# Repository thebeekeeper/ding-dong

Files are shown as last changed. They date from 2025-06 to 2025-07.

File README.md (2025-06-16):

## r0 Assembly Notes

- I forgot IO8 needs to be high at boot to be able to program the part.  Currently connected to c6, so I won't be able to use that output for now.
- I don't have the right inductors for the regulator on hand, so I used 33uH for both.  3.3v works, but 12v is down around 1v.  I'll try the correct inductor, but it might be easier to use a 12v wall wart.  Doorbell transformers give AC, so I'd have to convert it anyways.

## Changes for r1

- Removed the 12V regulator and added a barrel jack for power input.  
- Moved the `c6` signal from IO8 to IO18.  `IO8` needs to be high to program the esp32.  I'm not planning on using USB, so IO18 should be fine.
- Added a screw terminal to signal that the button has been pressed and wired it to IO19.  Added a pull-up on the signal, but I'm not sure if I'll need it.

I wasn't thinking about how the signal will come from the button, but in a typical doorbell, the button closes a circuit that will supply us with 12-14V AC.  I could put a bridge rectifier circuit in, and just use that but then I will only have power while the button is held down.  I think the best option would to use  12v wall wart and signal the bell to activate either by:
	1. A small circuit that detects when the low side of the doorbell transformer turns on and sends a 3.3v signal to my board
	2. Something wireless
So either way, the driver board will just expect a 3.3v signal and start the sequence when it gets the signal

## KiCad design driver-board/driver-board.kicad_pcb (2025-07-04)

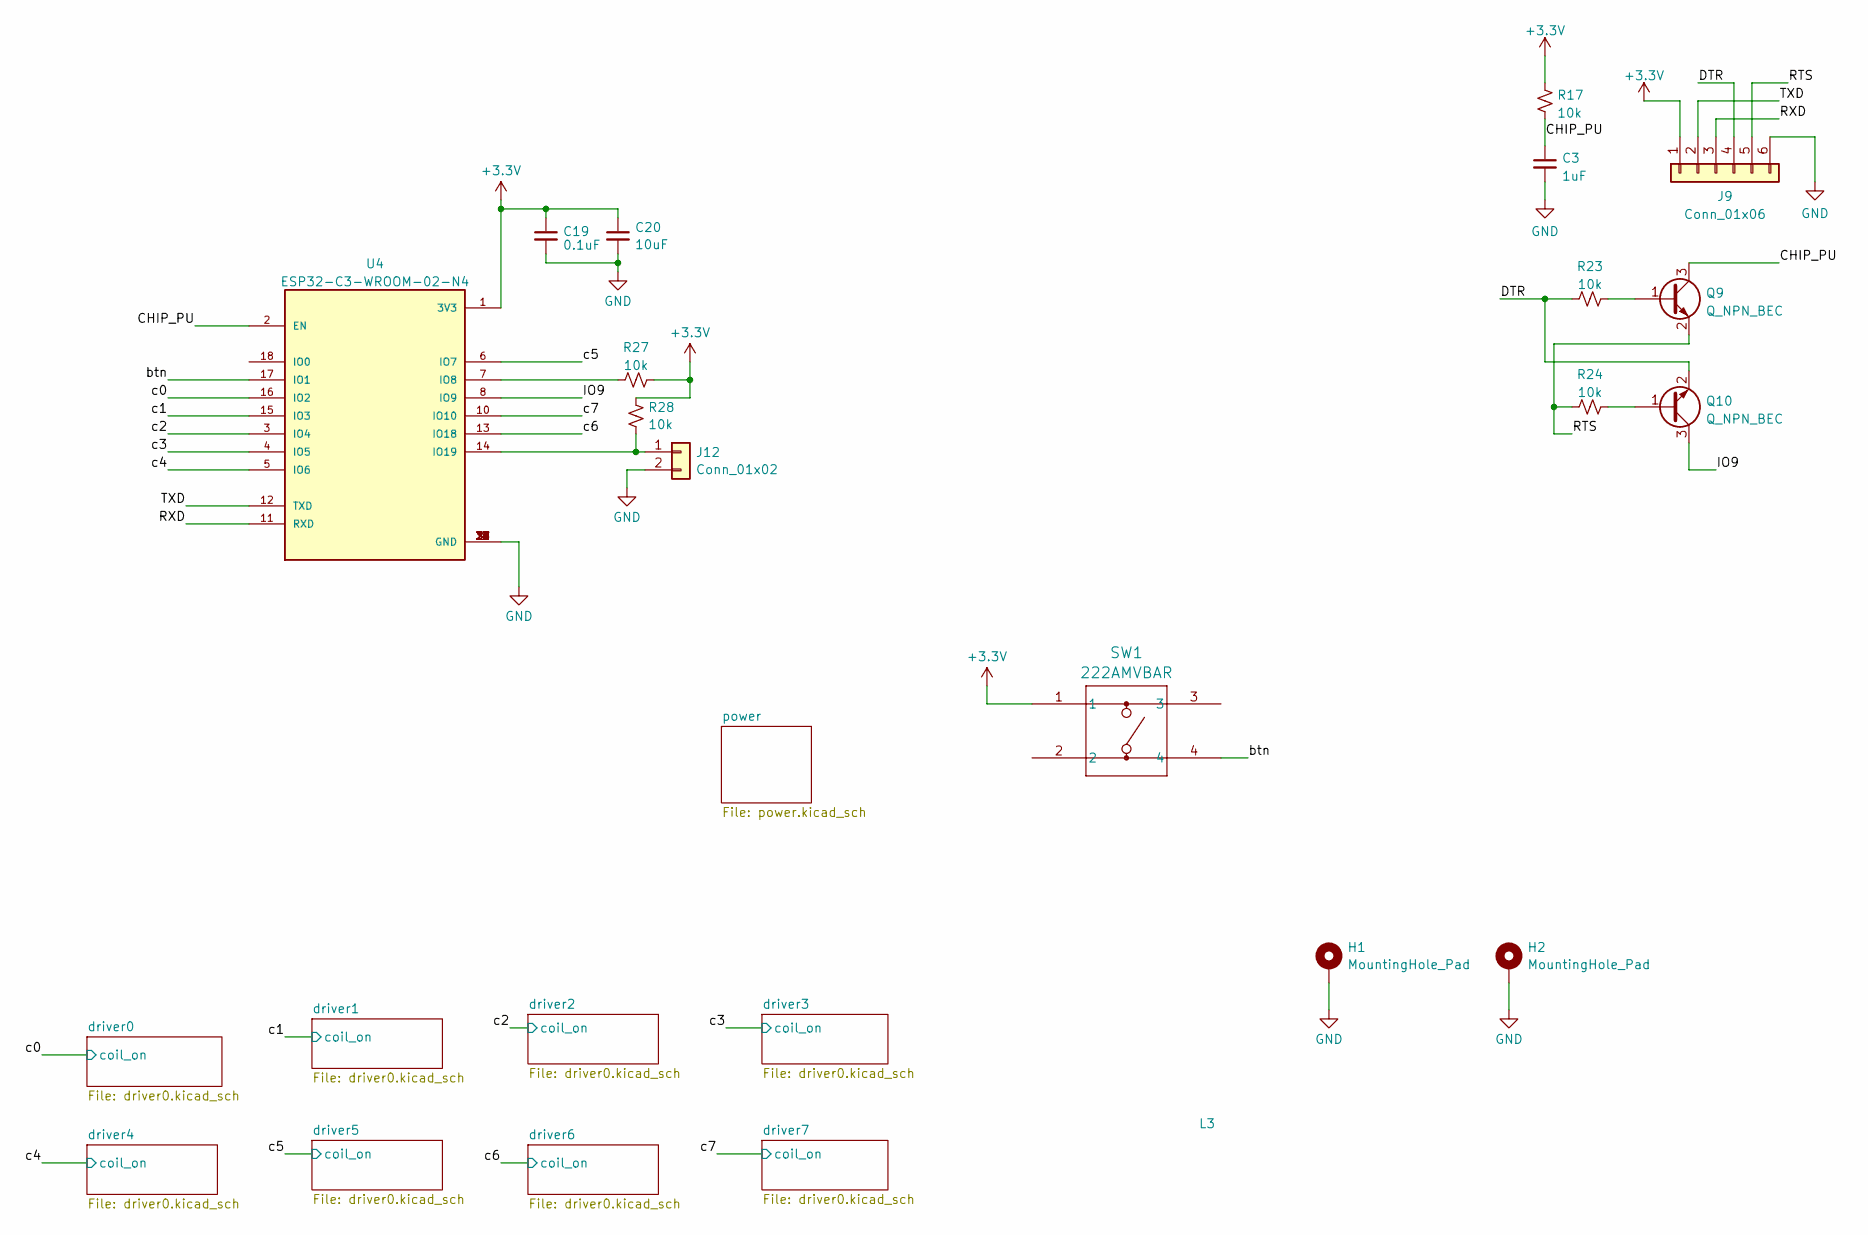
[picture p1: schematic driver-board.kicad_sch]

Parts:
C3: 1uF; C_0805_2012Metric; ManufacturerPartNumber CL21B105KOFNFNE
C19: 0.1uF; C_0603_1608Metric
C20: 10uF; C_0603_1608Metric
H1, H2: MountingHole_Pad; MountingHole_3.2mm_M3_Pad
J9: Conn_01x06; PinHeader_1x06_P2.54mm_Vertical; ManufacturerPartNumber TSW-106-07-G-S
J12: Conn_01x02; PhoenixContact_MCV_1,5_2-GF-3.81_1x02_P3.81mm_Vertical_Thre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
L3: bird
Q9, Q10: Q_NPN_BEC; SOT-23; ManufacturerPartNumber MMSS8050-H-TP
R17, R23, R24, R27, R28: 10k; R_0805_2012Metric; ManufacturerPartNumber RMCF0805FT10K0
SW1: 222AMVBAR; SO4_222A-M-V-B_CTS; ManufacturerPartNumber 222AMVBAR
U4: ESP32-C3-WROOM-02-N4; MODULE_ESP32-C3-WROOM-02-H4; ManufacturerPartNumber ESP32-C3-WROOM-02-N4

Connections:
+3.3V: C19.1, C20.1, J9.1, R17.1, R27.2, R28.2, SW1.1, U4.1 (3V3); also elsewhere on the board
/CHIP_PU: C3.1, Q9.3 (C), R17.2, U4.2 (EN)
/DTR: J9.4, Q10.2 (E), R23.1
/IO9: Q10.3 (C), U4.8 (IO9)
/RTS: J9.5, Q9.2 (E), R24.1
/RXD: J9.3, U4.11 (RXD)
/TXD: J9.2, U4.12 (TXD)
/btn: SW1.4, U4.17 (IO1)
/c0: U4.16 (IO2); also elsewhere on the board
/c1: U4.15 (IO3); also elsewhere on the board
/c2: U4.3 (IO4); also elsewhere on the board
/c3: U4.4 (IO5); also elsewhere on the board
/c4: U4.5 (IO6); also elsewhere on the board
/c5: U4.6 (IO7); also elsewhere on the board
/c6: U4.13 (IO18); also elsewhere on the board
/c7: U4.10 (IO10); also elsewhere on the board
GND: C3.2, C19.2, C20.2, H1.1, H2.1, J9.6, J12.2, U4.9 (GND), U4.19 (GND), U4.20 (GND), U4.21 (GND), U4.22 (GND), U4.23 (GND), U4.24 (GND), U4.25 (GND), U4.26 (GND), U4.27 (GND), U4.28 (GND), U4.29 (GND), U4.30 (GND), U4.31 (GND), U4.32 (GND), U4.33 (GND), U4.34 (GND), U4.35 (GND), U4.36 (GND), U4.37 (GND), U4.38 (GND), U4.39 (GND); also elsewhere on the board
unnamed: J12.1, R28.1, U4.14 (IO19)
unnamed: Q9.1 (B), R23.2
unnamed: Q10.1 (B), R24.2
unnamed: R27.1, U4.7 (IO8)

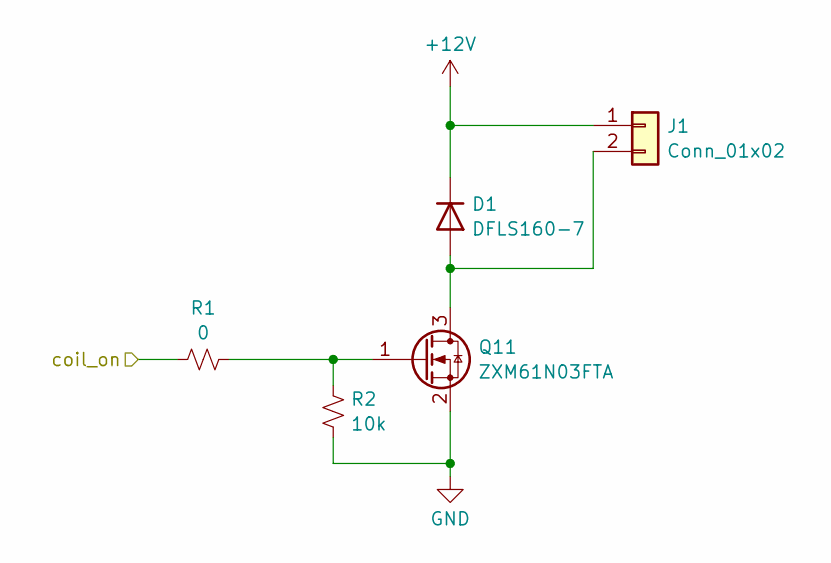
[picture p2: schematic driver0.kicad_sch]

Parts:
D1: DFLS160-7; D_PowerDI-123
J1: Conn_01x02; JST_PH_B2B-PH-K_1x02_P2.00mm_Vertical
Q11: ZXM61N03FTA; SOT-23-3
R1: 0; R_0805_2012Metric
R2: 10k; R_0805_2012Metric

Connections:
+12V: D1.1 (K), J1.1; also elsewhere on the board
/c0: R1.1; also elsewhere on the board
GND: Q11.2 (S), R2.1; also elsewhere on the board
unnamed: D1.2 (A), J1.2, Q11.3 (D)
unnamed: Q11.1 (G), R1.2, R2.2

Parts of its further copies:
D2, D3, D4, D5, D6, D7, D8: DFLS160-7; D_PowerDI-123
J2, J3, J4, J5, J6, J7, J8: Conn_01x02; JST_PH_B2B-PH-K_1x02_P2.00mm_Vertical
Q12, Q13, Q14, Q15, Q16, Q17, Q18: ZXM61N03FTA; SOT-23-3
R4, R6, R8, R10, R12, R14, R16: 10k; R_0805_2012Metric

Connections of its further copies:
+12V: D2.1 (K), D3.1 (K), D4.1 (K), D5.1 (K), D6.1 (K), D7.1 (K), D8.1 (K), J2.1, J3.1, J4.1, J5.1, J6.1, J7.1, J8.1; also elsewhere on the board
GND: Q12.2 (S), Q13.2 (S), Q14.2 (S), Q15.2 (S), Q16.2 (S), Q17.2 (S), Q18.2 (S), R4.1, R6.1, R8.1, R10.1, R12.1, R14.1, R16.1; also elsewhere on the board
unnamed: D2.2 (A), J2.2, Q12.3 (D)
unnamed: D3.2 (A), J3.2, Q13.3 (D)
unnamed: D4.2 (A), J4.2, Q14.3 (D)
unnamed: D5.2 (A), J5.2, Q15.3 (D)
unnamed: D6.2 (A), J6.2, Q16.3 (D)
unnamed: D7.2 (A), J7.2, Q17.3 (D)
unnamed: D8.2 (A), J8.2, Q18.3 (D)
unnamed 31: Q12.1 (G), R4.2; also elsewhere on the board
unnamed 32: Q13.1 (G), R6.2; also elsewhere on the board
unnamed 33: Q14.1 (G), R8.2; also elsewhere on the board
unnamed 34: Q15.1 (G), R10.2; also elsewhere on the board
unnamed 35: Q16.1 (G), R12.2; also elsewhere on the board
unnamed 36: Q17.1 (G), R14.2; also elsewhere on the board
unnamed 37: Q18.1 (G), R16.2; also elsewhere on the board

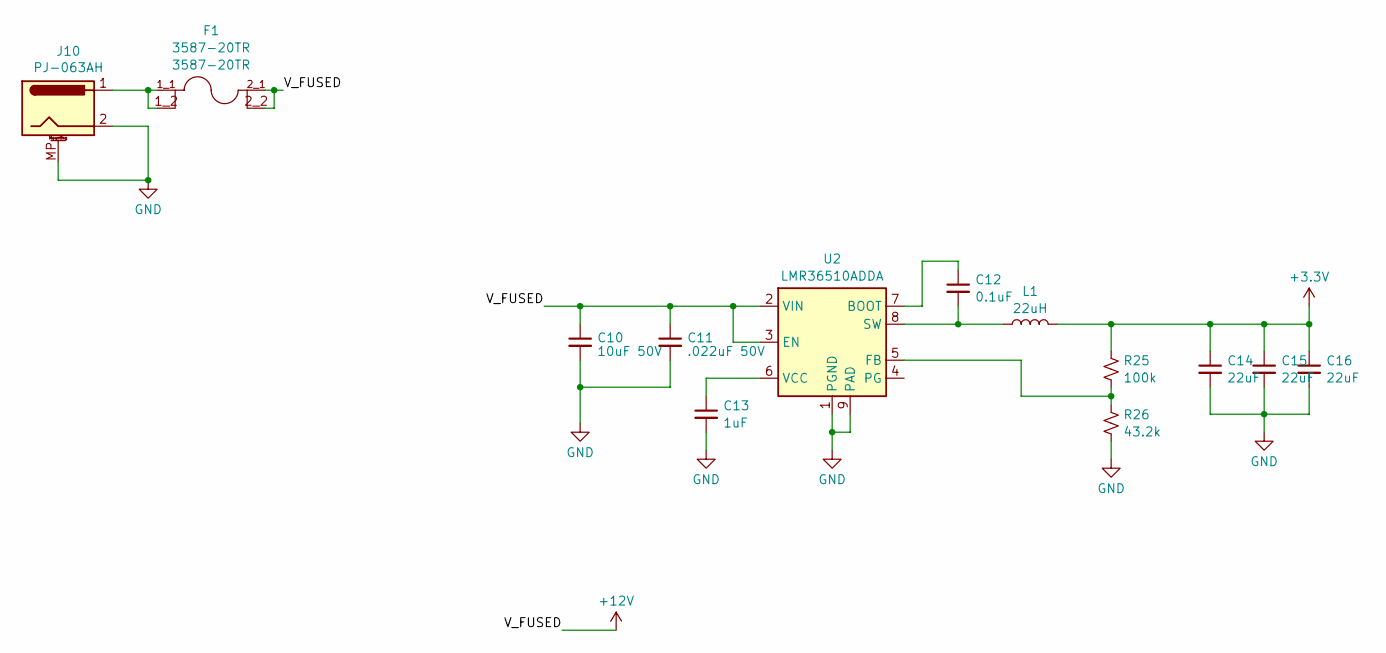
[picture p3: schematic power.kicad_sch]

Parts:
C10: 10uF 50V; C_1206_3216Metric; ManufacturerPartNumber CL31A106MBHNNNE
C11: .022uF 50V; C_1206_3216Metric; ManufacturerPartNumber 12065C223KAT4A
C12: 0.1uF; C_0805_2012Metric
C13: 1uF; C_0805_2012Metric
C14, C15, C16: 22uF; C_0805_2012Metric
F1: 3587-20TR; FUSE_3587; ManufacturerPartNumber 3587-20TR
J10: PJ-063AH; BarrelJack_CUI_PJ-063AH_Horizontal; ManufacturerPartNumber PJ-063AH
L1: 22uH; SRN3010C2R2M
R25: 100k; R_0805_2012Metric; ManufacturerPartNumber RMCF0805FT10K0
R26: 43.2k; R_0805_2012Metric; ManufacturerPartNumber RMCF0805FT10K0
U2: LMR36510ADDA; Texas_HTSOP-8-1EP_3.9x4.9mm_P1.27mm_EP2.95x4.9mm_Mask2.4x3.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

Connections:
+3.3V: C14.1, C15.1, C16.1, L1.2, R25.2; also elsewhere on the board
+12V: C10.1, C11.1, F1.2_1, F1.2_2, U2.2 (VIN), U2.3 (EN); also elsewhere on the board
GND: C10.2, C11.2, C13.2, C14.2, C15.2, C16.2, J10.2, J10.MP (MountPin), R26.1, U2.1 (PGND), U2.9 (PAD); also elsewhere on the board
unnamed: F1.1_1, F1.1_2, J10.1
unnamed: C12.1, U2.7 (BOOT)
unnamed: R25.1, R26.2, U2.5 (FB)
unnamed: C12.2, L1.1, U2.8 (SW)
unnamed: C13.1, U2.6 (VCC)

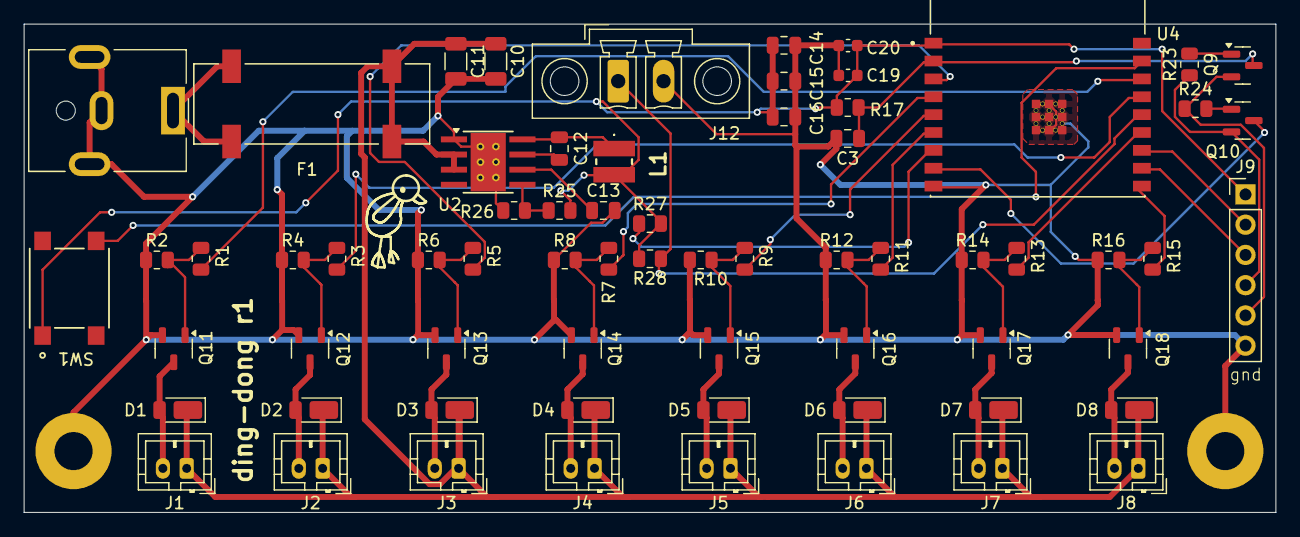
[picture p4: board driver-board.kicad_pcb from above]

Board: 2 copper layers, 105.1 x 41.0 mm, 70 parts (0 on the bottom side), 43 nets.

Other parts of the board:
R3, R5, R7, R9, R11, R13, R15: 4.7k; R_0805_2012Metric

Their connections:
/c1: R3.1; also elsewhere on the board
/c2: R5.1; also elsewhere on the board
/c3: R7.1; also elsewhere on the board
/c4: R9.1; also elsewhere on the board
/c5: R11.1; also elsewhere on the board
/c6: R13.1; also elsewhere on the board
/c7: R15.1; also elsewhere on the board
unnamed 31: R3.2; also elsewhere on the board
unnamed 32: R5.2; also elsewhere on the board
unnamed 33: R7.2; also elsewhere on the board
unnamed 34: R9.2; also elsewhere on the board
unnamed 35: R11.2; also elsewhere on the board
unnamed 36: R13.2; also elsewhere on the board
unnamed 37: R15.2; also elsewhere on the board

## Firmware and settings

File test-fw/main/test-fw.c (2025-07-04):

#include "sdkconfig.h"
#include "freertos/FreeRTOS.h"
#include "freertos/task.h"
#include "esp_system.h"
#include "esp_log.h"
#include "esp_err.h"
#include "esp_check.h"
#include "driver/gpio.h"

#define TAG "ding-dong"

#define CHANNEL_COUNT 8
static uint8_t pins[CHANNEL_COUNT] = { 2, 3, 4, 5, 6, 7, 18, 10 };
void init_io(void);

void app_main(void)
{
    ESP_LOGI(TAG, "hello");
    init_io();

    uint8_t idx = 0;
    while(1) {
        /*ESP_LOGI(TAG, "high");
        gpio_set_level(pins[0], 1);
        vTaskDelay(1000 / portTICK_PERIOD_MS);
        ESP_LOGI(TAG, "low");
        gpio_set_level(pins[0], 0);
        vTaskDelay(1000 / portTICK_PERIOD_MS);
        */

        ESP_LOGI(TAG, "Actuating %u", idx);
        gpio_set_level(pins[idx], 1);
        vTaskDelay(500 / portTICK_PERIOD_MS);
        gpio_set_level(pins[idx], 0);
        if (idx == CHANNEL_COUNT-1)
        {
            idx = 0;
        }
        else
        {
            idx++;
        }
    }
}

void init_io(void) {

    size_t i;
    gpio_config_t io_conf = {};
    io_conf.intr_type = GPIO_INTR_DISABLE;
    io_conf.mode = GPIO_MODE_OUTPUT;
    io_conf.pull_down_en = 1;
    io_conf.pull_up_en = 0;
    for(i = 0 ; i < CHANNEL_COUNT ; i++) {
        io_conf.pin_bit_mask = (1ULL << pins[i]);
        gpio_config(&io_conf);
    }
}

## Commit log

2025-06-16 initial add
    [driver-board-B_Cu.gbr, driver-board-B_Mask.gbr, driver-board-B_Paste.gbr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]
2025-06-16 schematic updates for r1
    [driver-board.kicad_sch, power.kicad_sch]
2025-06-16 updated layout
    [driver-board.kicad_pcb, power.kicad_sch]
2025-07-04 new board
    [driver-board-B_Cu.gbr, driver-board-B_Mask.gbr, driver-board-B_Paste.gbr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]
